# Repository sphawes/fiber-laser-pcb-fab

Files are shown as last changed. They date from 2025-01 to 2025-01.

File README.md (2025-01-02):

# How to make PCBs on a Fiber Laser

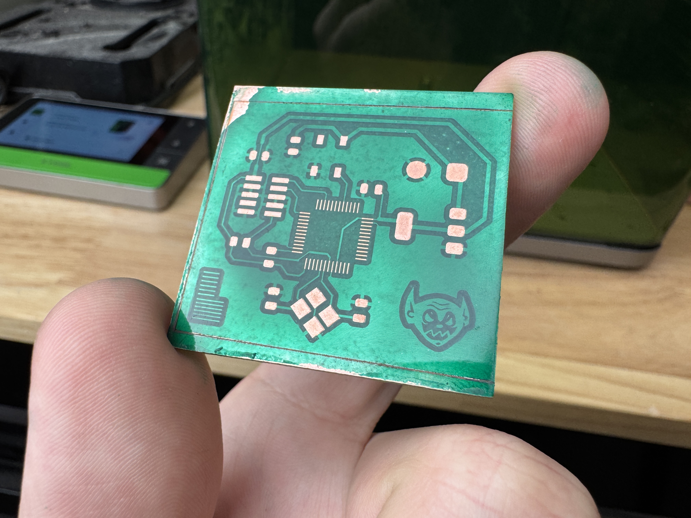
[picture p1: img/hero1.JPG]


This repo contains instructions and settings for fabricating single-sided PCBs on an xTool F1 Ultra fiber laser.

## Parts Needed

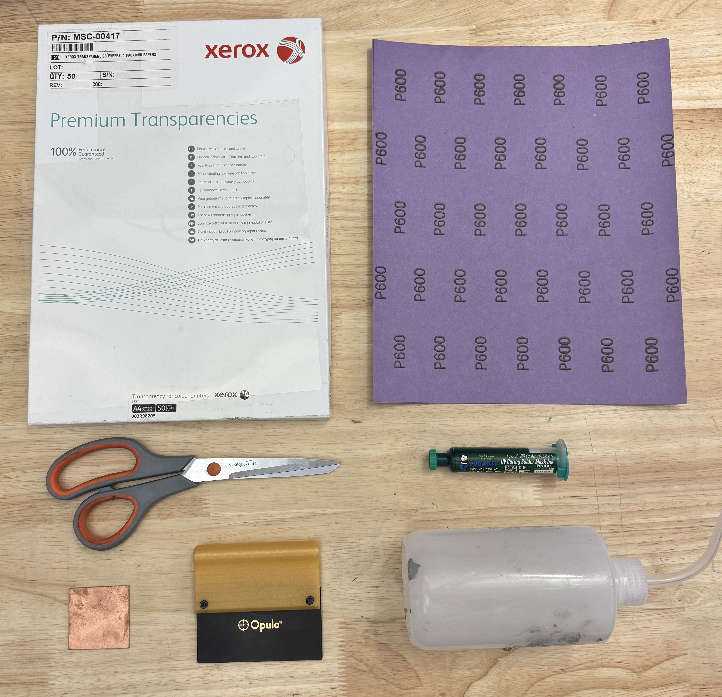
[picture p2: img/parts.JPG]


Aside from the fiber laser, you'll need:

- A transparency sheet (or framed silkscreen)
- 600 grit sandpaper
- Scissors
- Soldermask
- FR1 Copper Clad Board
- Squeegee / scraper
- Isopropyl Alcohol

You can also download and 3D print the jig for cutting and aligning boards for the F1 from this repository. You'll just need some M4 bolts, 2mm dowel pins, and [this heatsink](https://amzn.to/4a2UuFx).

## File Prep

In order to have the xTool software correctly process your files, there's some specific settings for exporting your boad that will render the correct image.

1. In KiCAD, go to `File -> Plot`.
2. Switch `Plot Format` to "DXF." Only include the F.Cu layer. Under `DXF Options`, check `Plot graphic items using their contours` and `Export Units` to "Millimeters." Make sure you've selected "Edge.Cuts" under "Plot on All Layers" not shown in this screenshot, you'll have to scroll down. This will help with alignment later. Click the `Plot` button.

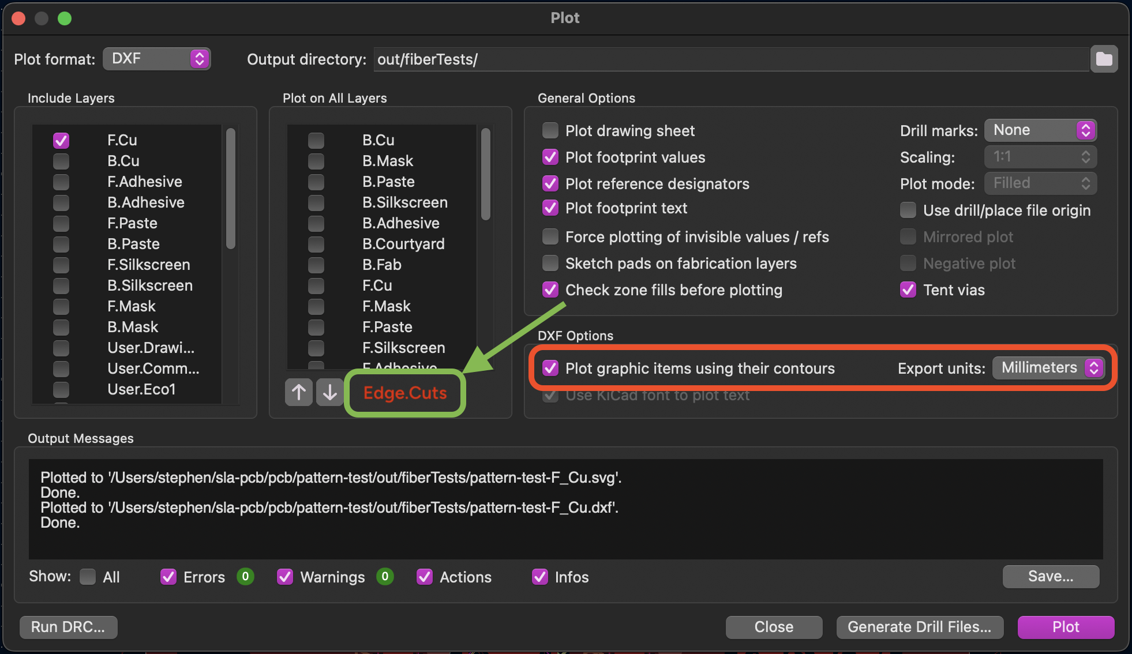
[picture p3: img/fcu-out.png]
    

1. With the same settings, select only the `F.Mask` layer and click the `Plot` button.

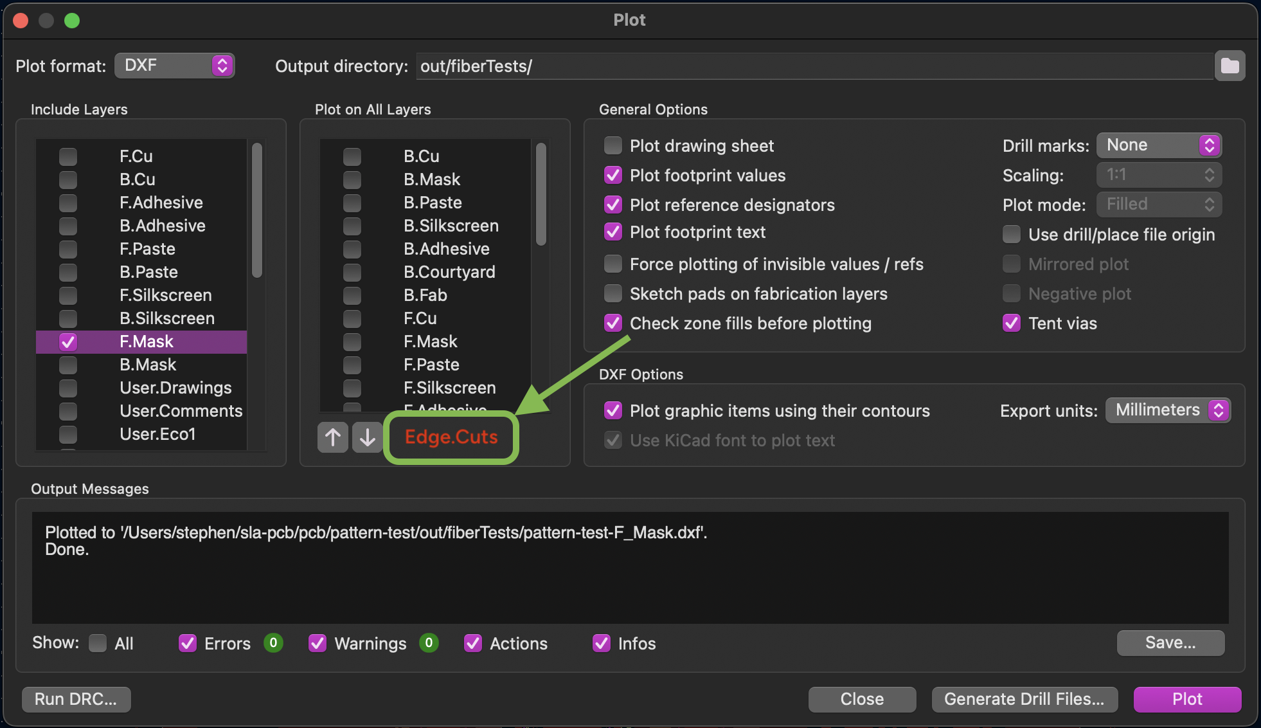
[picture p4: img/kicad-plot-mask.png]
    

## Removing Copper

1. Give your board a good sanding. While not strictly necessary, it helps quite a bit when inspecting the board and determining trace quality.

2. Mount the alignment bracket in the location that puts your board as close to the exact center of the work area as possible.

    

3. Pick the most square corner, and push it into the corner, making sure it does not come away from the bracket when pulling your hand away.

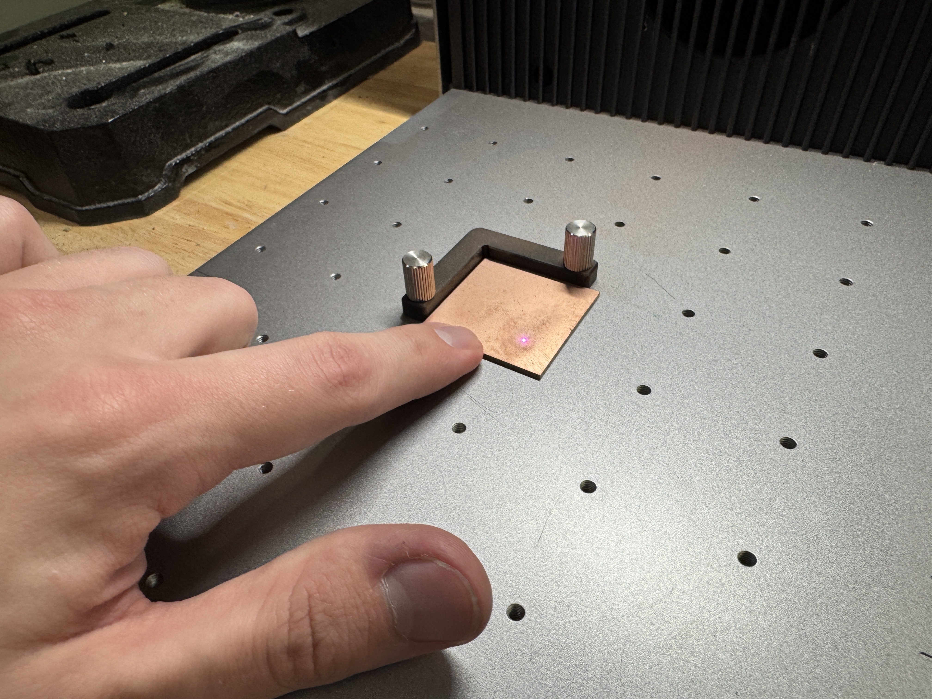
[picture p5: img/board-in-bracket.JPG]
    

4. **Gently** slide down the cover, as to not disturb the board's position.

5. In xTool Create, import the front copper DXF you exported. It should look like the image below.

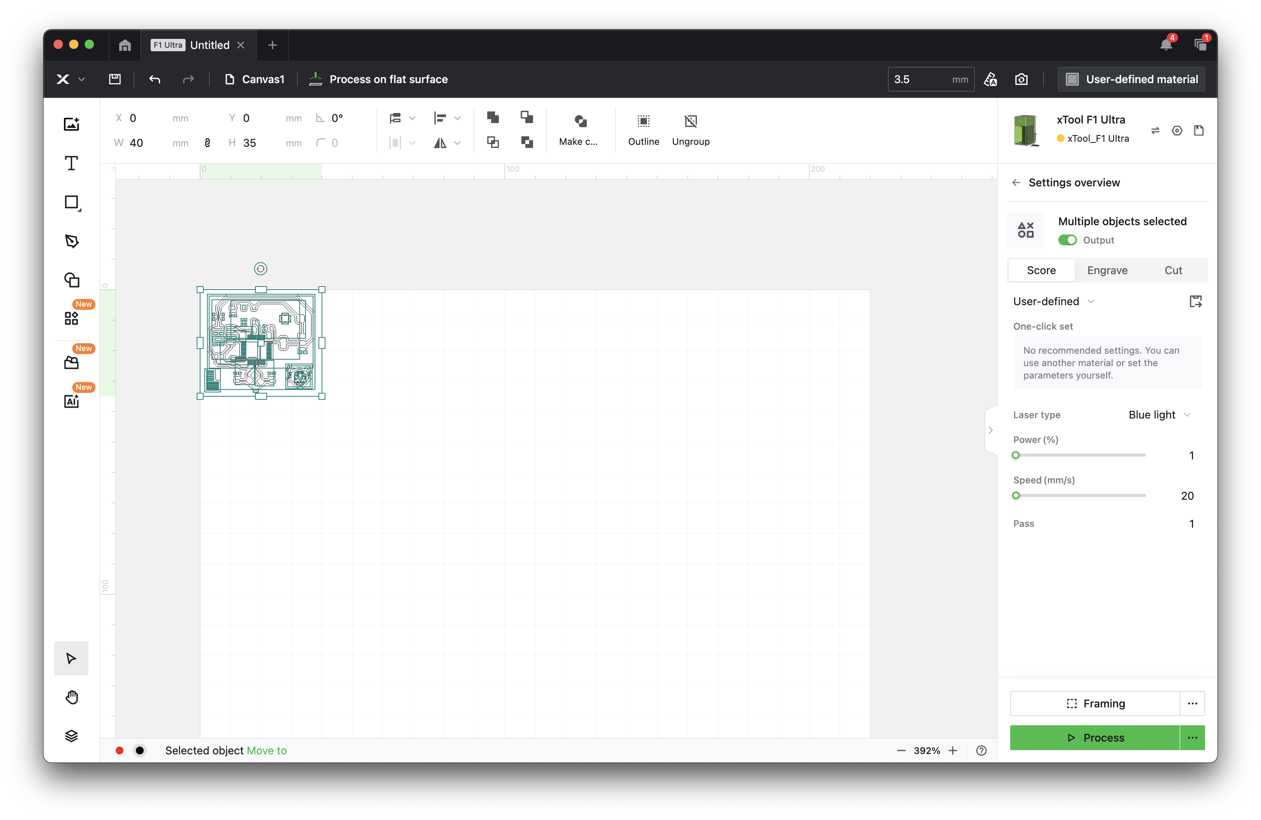
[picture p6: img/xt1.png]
    

6. Select your imported design and select the `Ungroup` button

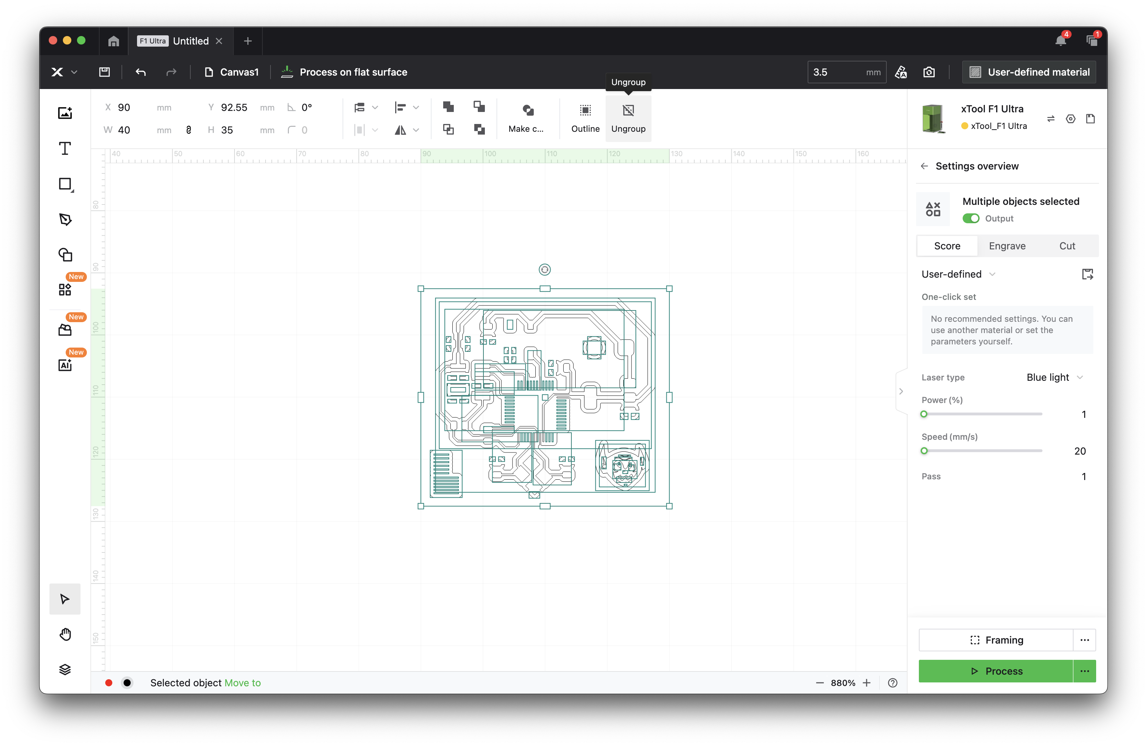
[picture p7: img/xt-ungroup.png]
    

7. With the design components ungrouped, select the outer edge cuts line, right click, and move it to a different color. I choose red for this step

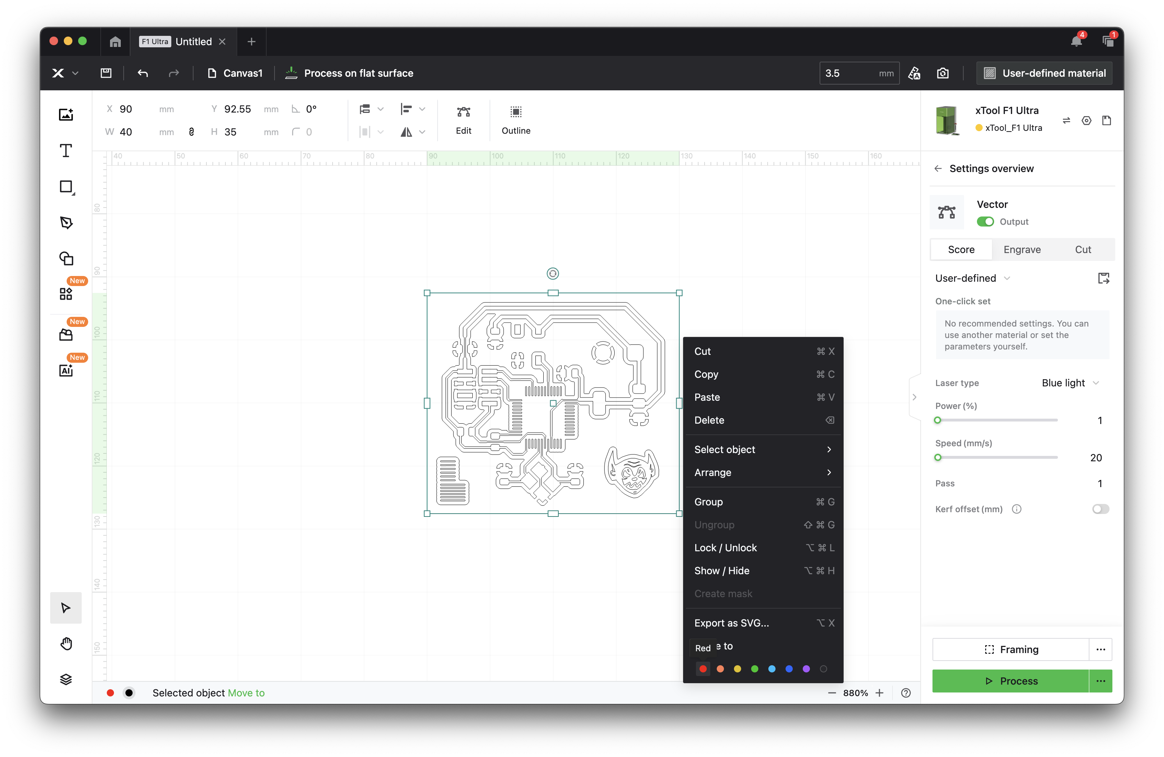
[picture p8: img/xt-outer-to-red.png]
    

8. Select all the inner components of the design (I do this by selecting *all*, then shift-clicking the outer edge).

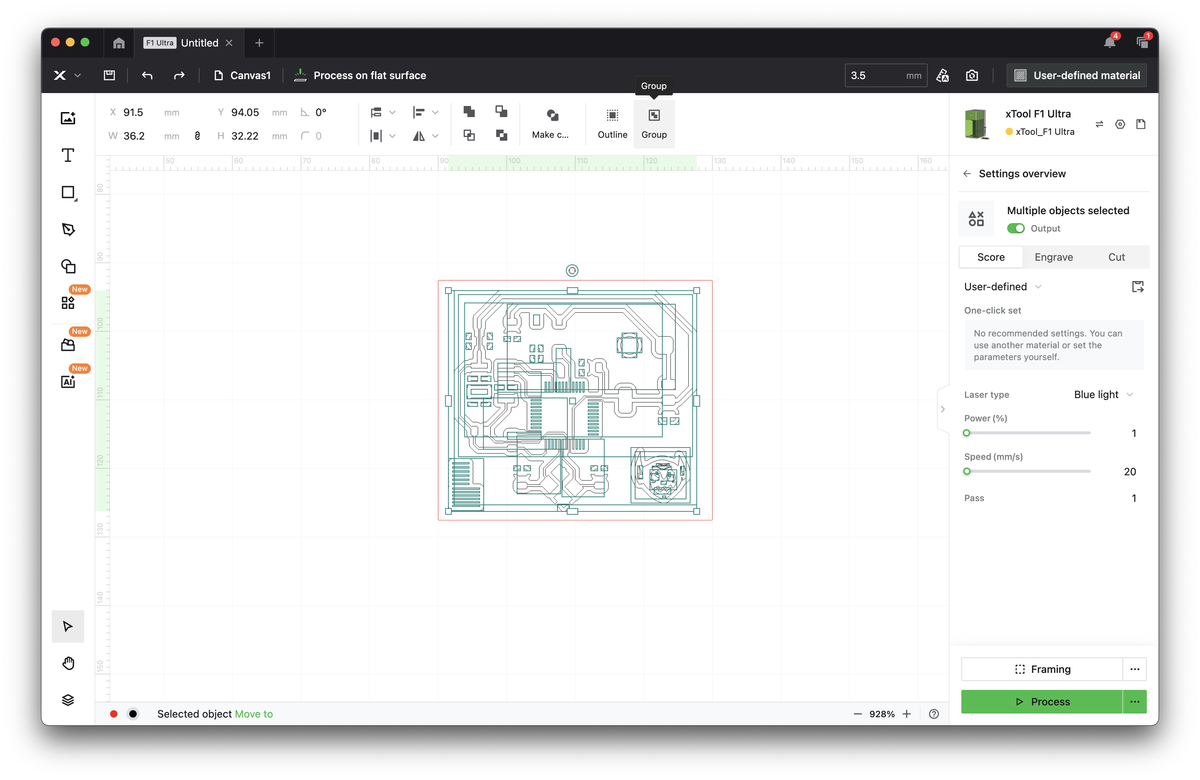
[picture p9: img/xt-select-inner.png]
    

9.  Combine all of the inner design components by clicking the `Make Compound Vector` button.

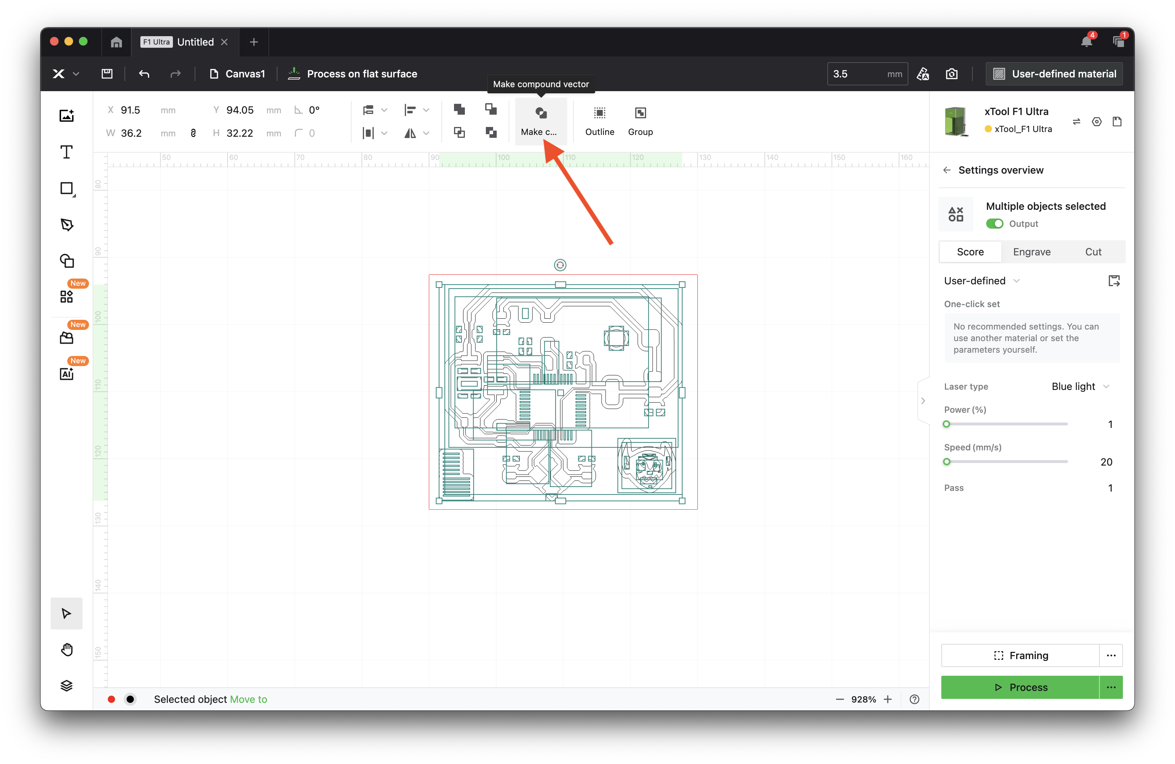
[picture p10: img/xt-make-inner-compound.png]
    

10. With the center selected, select the `Engrave` option on the right, and the board should be filled in and look like the image below:

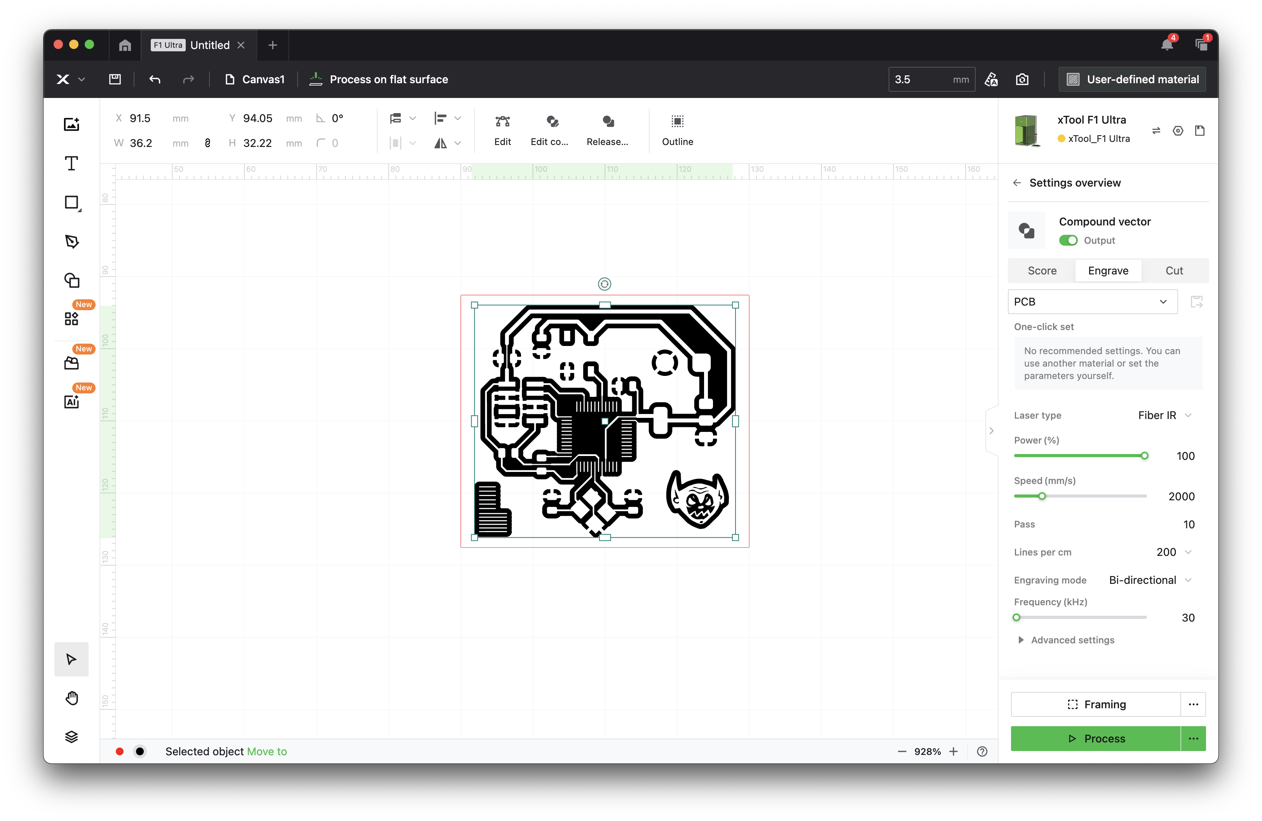
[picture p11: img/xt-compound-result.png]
    

11. Import the `settings.json` file in this repository using the settings manager.

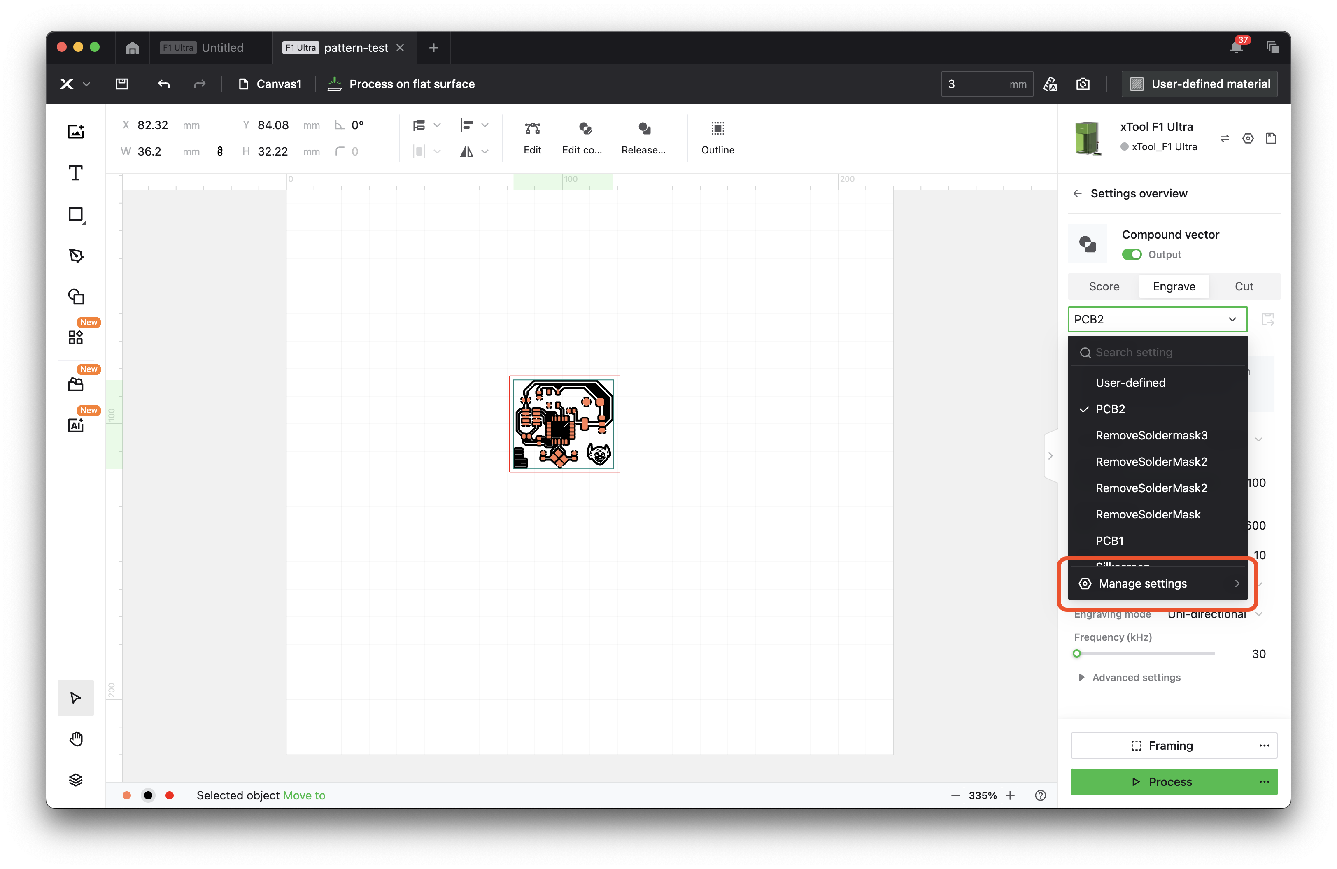
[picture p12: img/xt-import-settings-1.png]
    
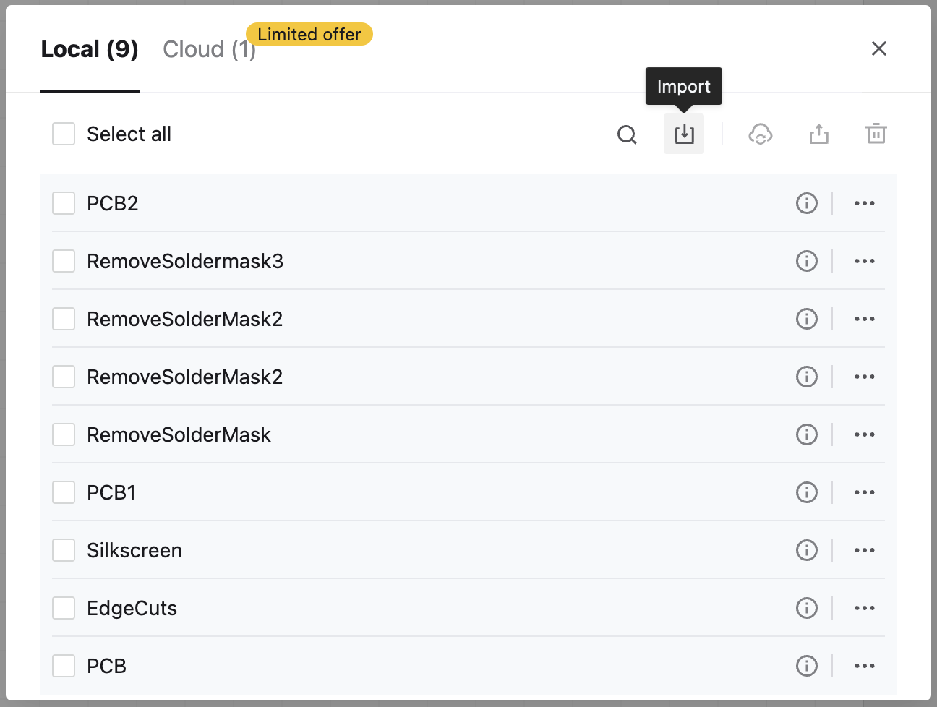
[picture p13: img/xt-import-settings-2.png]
    

12. For the inner section, select the `Traces` settings. They're also shown below if you don't want to import them directly.

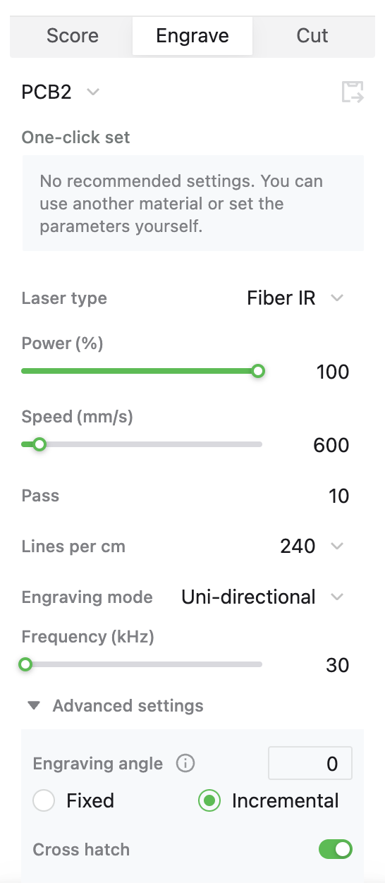
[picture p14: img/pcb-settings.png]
    

13. Use the "Capture Image" feature and the "Framing" feature to align your design onto the copper clad you put in the machine.

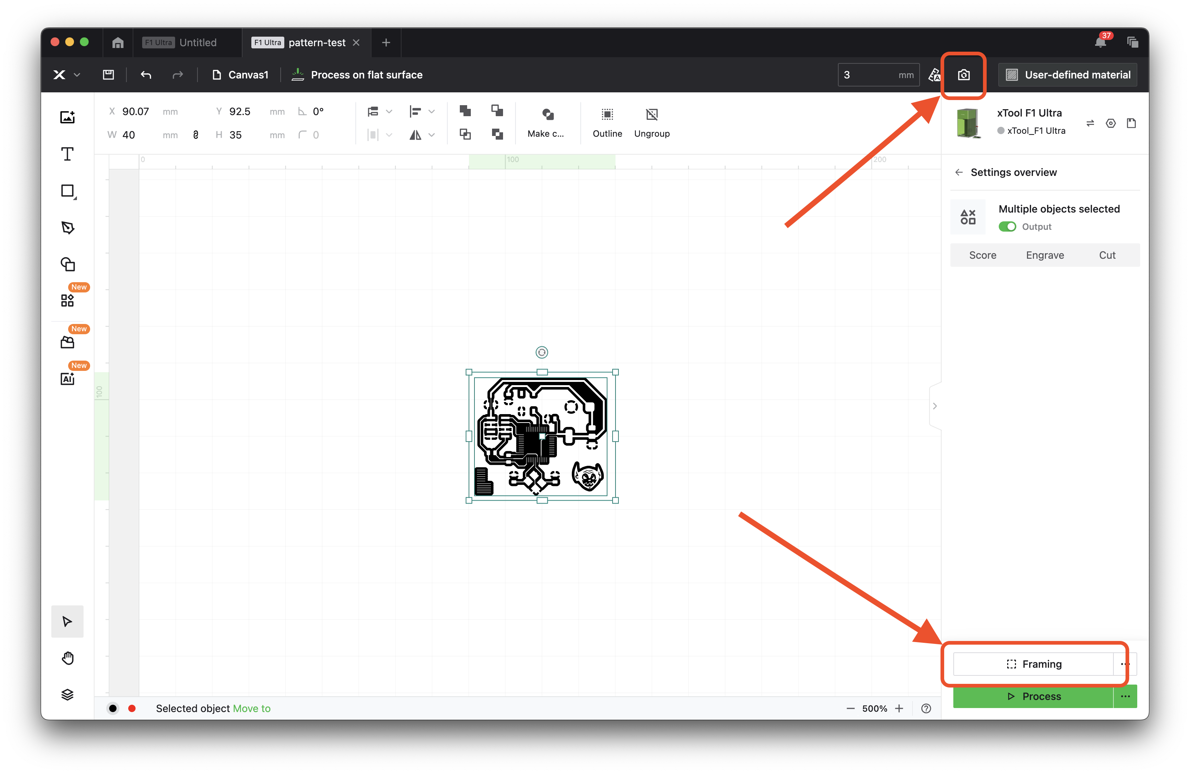
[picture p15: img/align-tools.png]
    

14. Run the job!

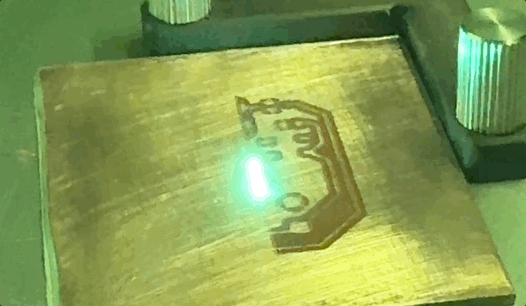
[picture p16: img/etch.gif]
    

## Board Clean

1. Your board will have some flashing and burrs on the edge of the engravings. Use some 600 grit sandpaper to remove the rough edges. you should have a smooth, clean, copper result.

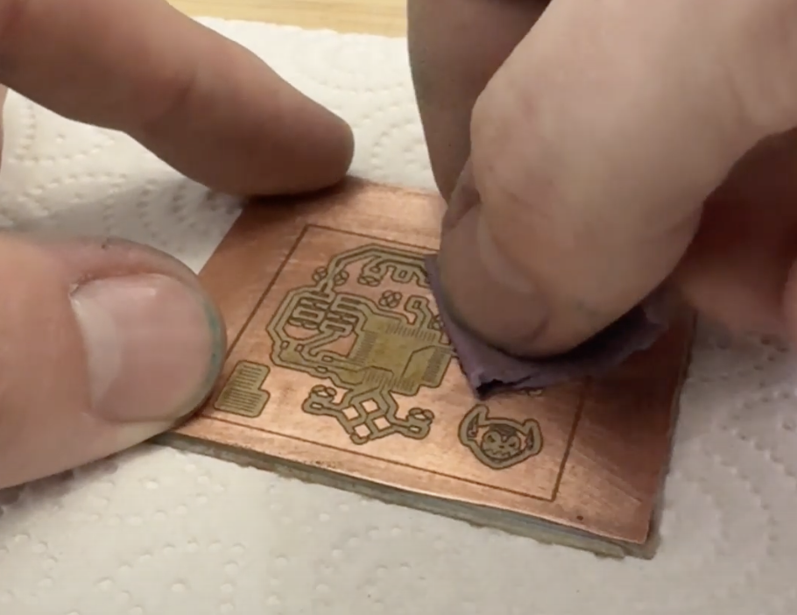
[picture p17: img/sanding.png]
    
    

1. Clean your board with Isopropyl alcohol to remove any debris and dust.

## Apply Soldermask

1. Acquire UV curable solder mask. I recommend [Mechanic Solder Mask](https://amzn.to/3DEGndt). It cures well and applies easily.

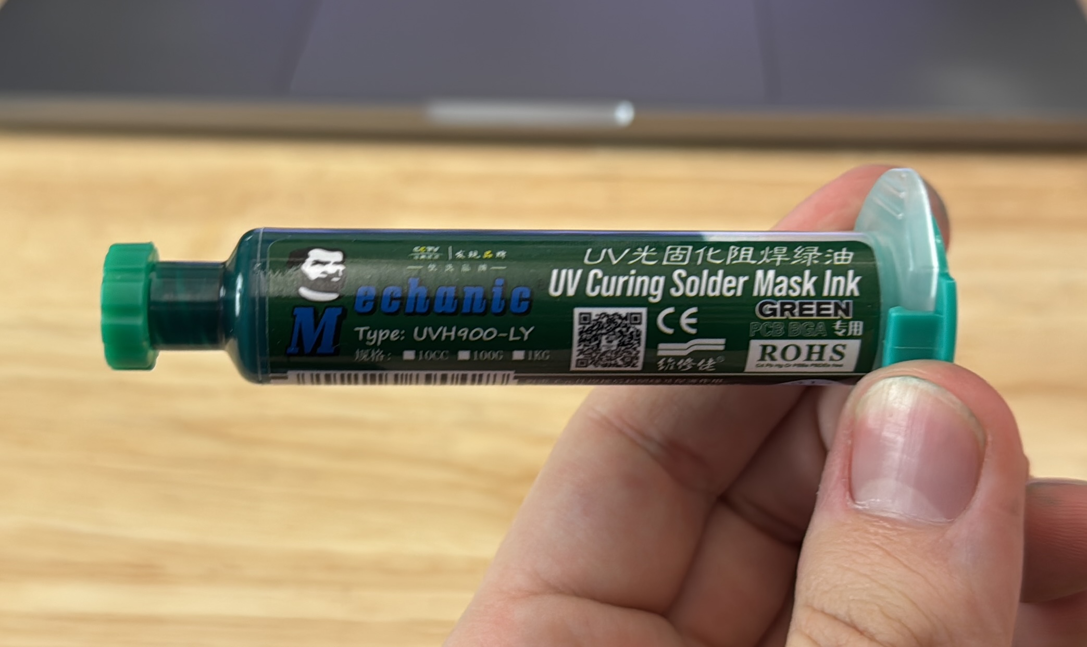
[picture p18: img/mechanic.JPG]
    

1. Apply a bead across the board.

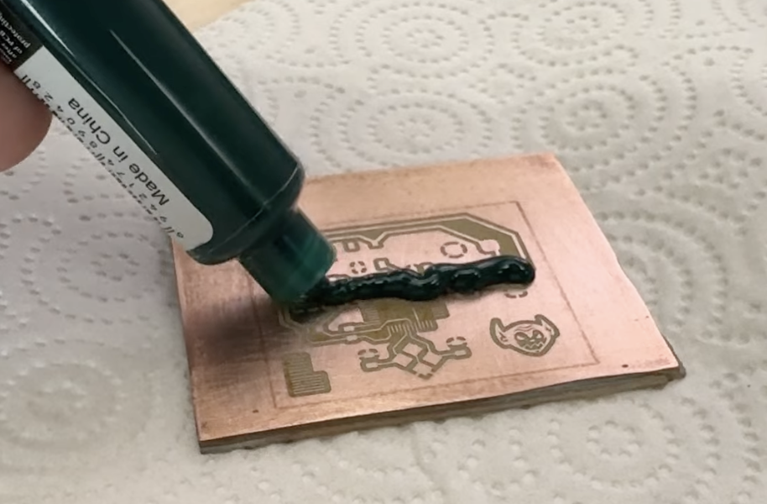
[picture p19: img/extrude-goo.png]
    

1. Place a transparency sheet on top.

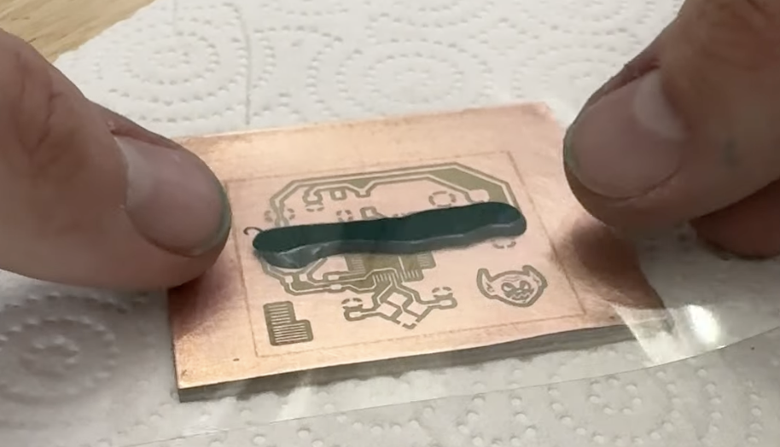
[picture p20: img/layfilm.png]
    

1. Squeegee it as evenly as possible across the board.

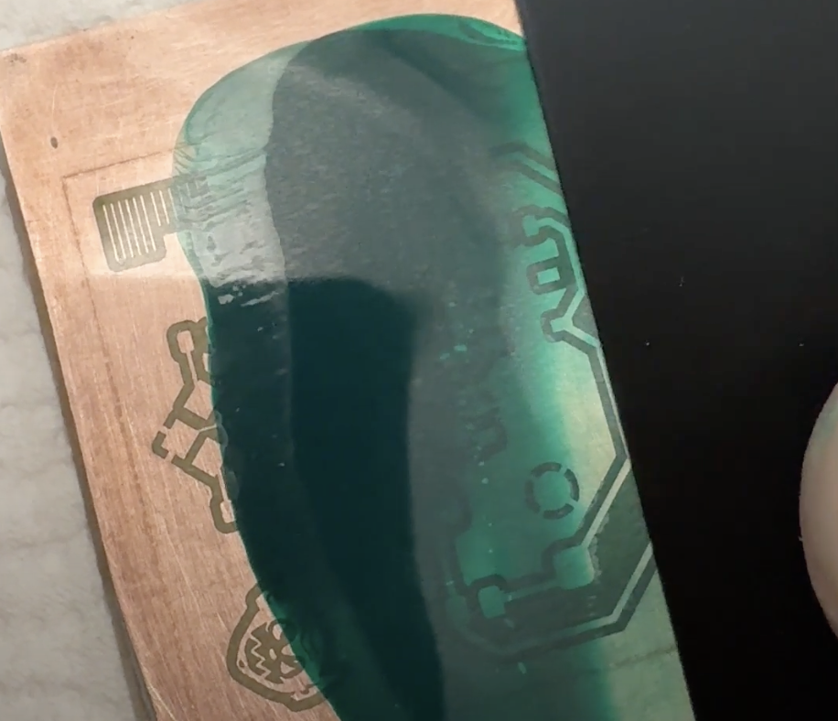
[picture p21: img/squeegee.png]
    
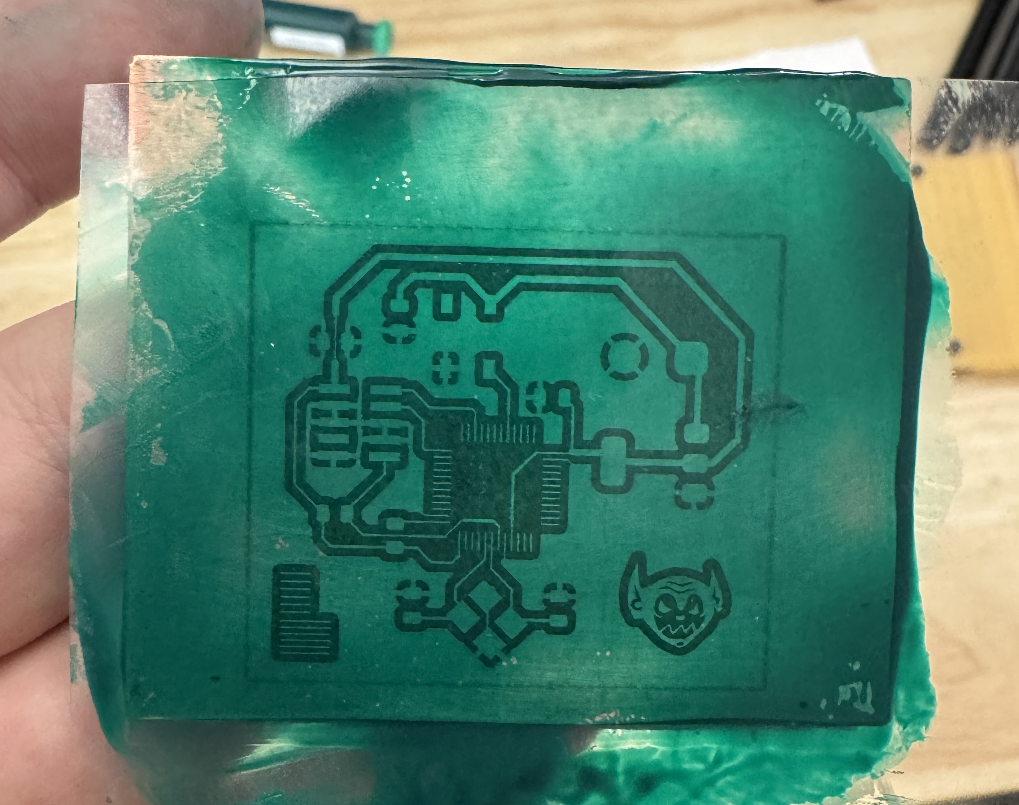
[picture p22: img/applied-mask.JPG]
    

1. An alternative solution is to use a [silkscreen frame](https://amzn.to/4fJWfZw). In my experience, this is a much more consistent way of applying the mask, and you get a nice matte finish after curing.

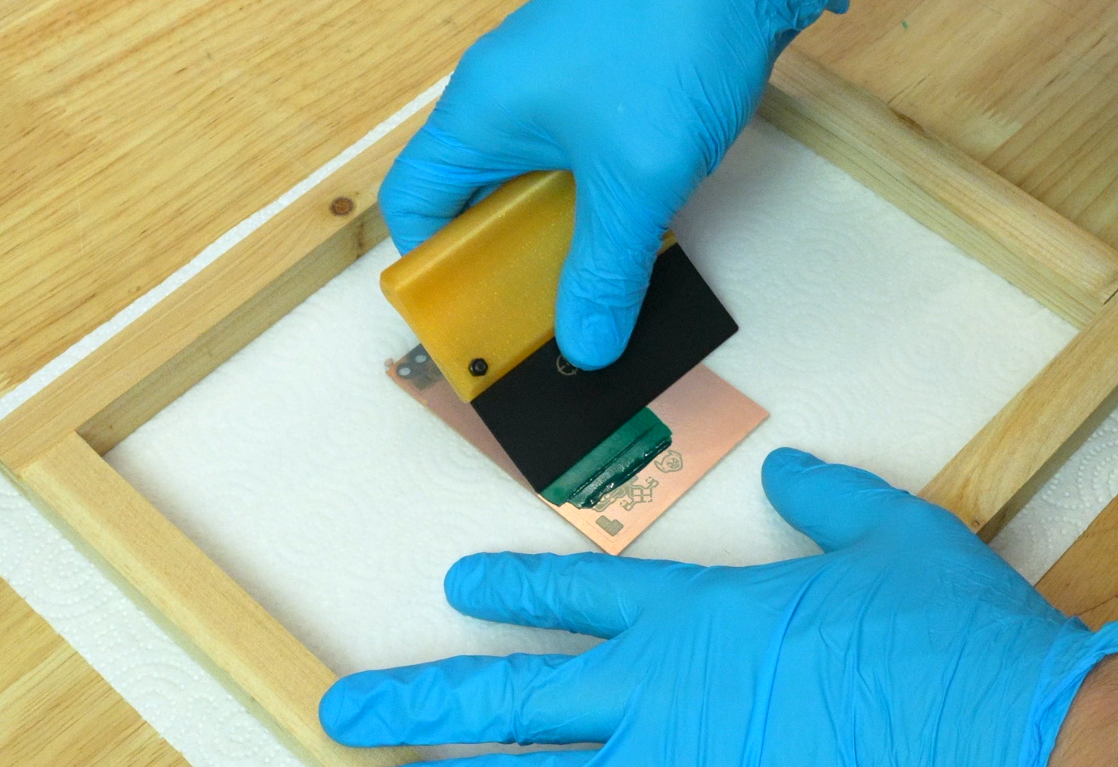
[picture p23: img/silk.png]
    
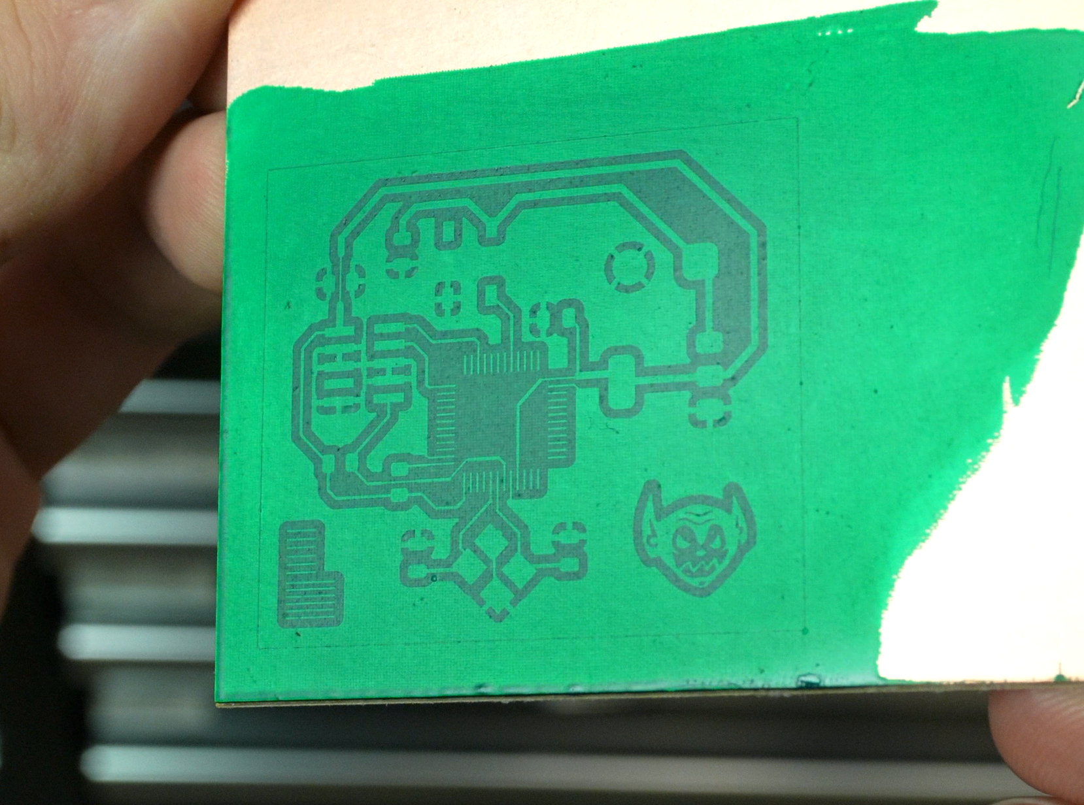
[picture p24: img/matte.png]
    

2. Cure the soldermask. A great, cheap solution is a UV nail polish curing station. [This one](https://amzn.to/3C092ZN) worked great for me.

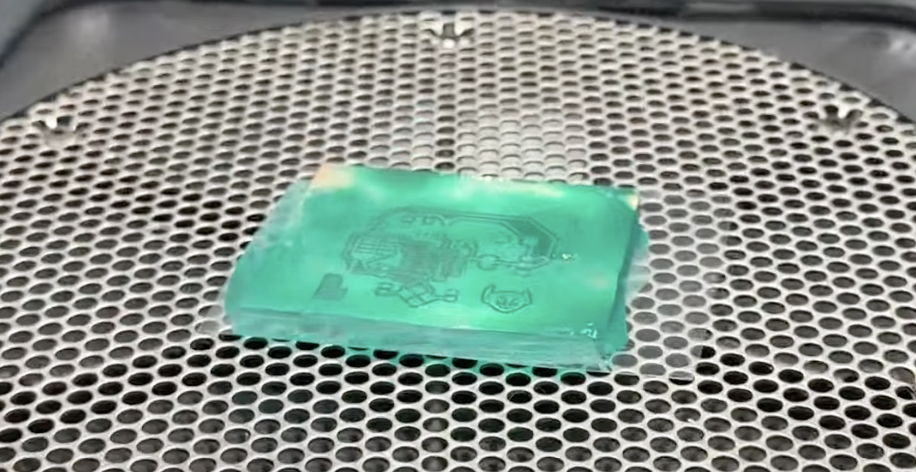
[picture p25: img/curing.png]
    

## Removing Soldermask

1. Import the F.Mask DXF you exported.

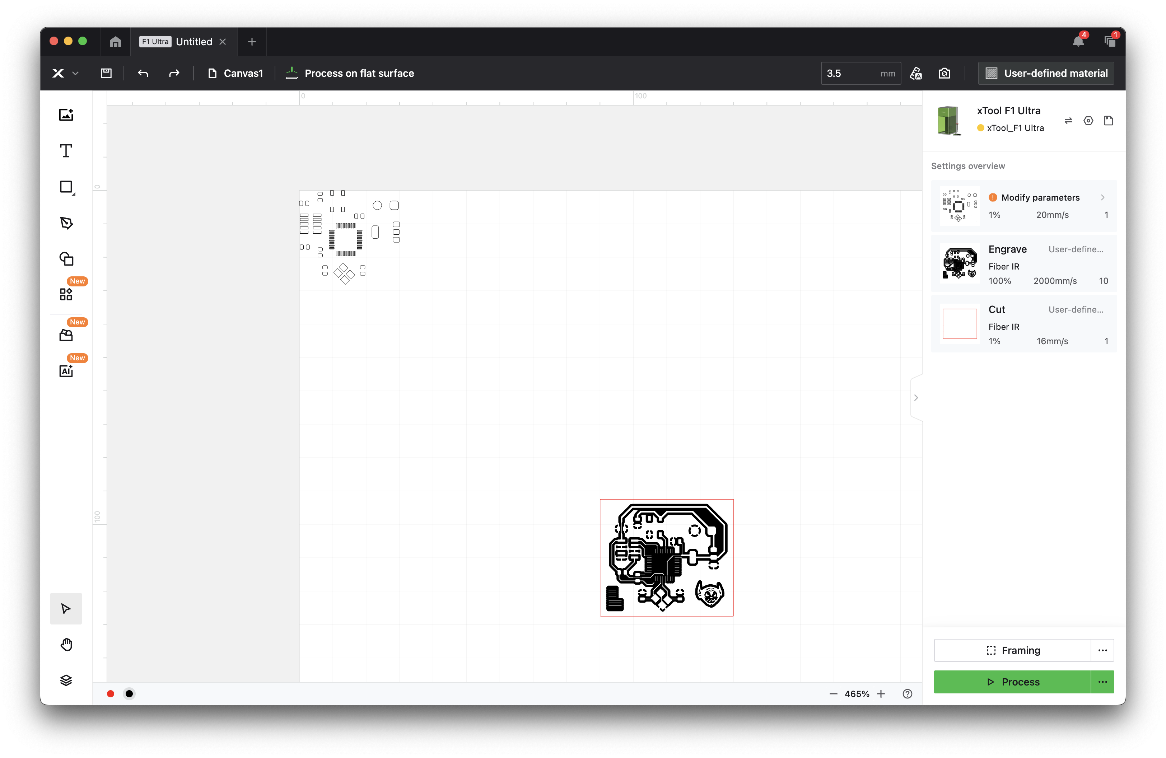
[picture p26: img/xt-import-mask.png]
    

1. Select all mask components, then combine them using the button along the top toolbar, and select the "engrave" job type in the menu on the right.

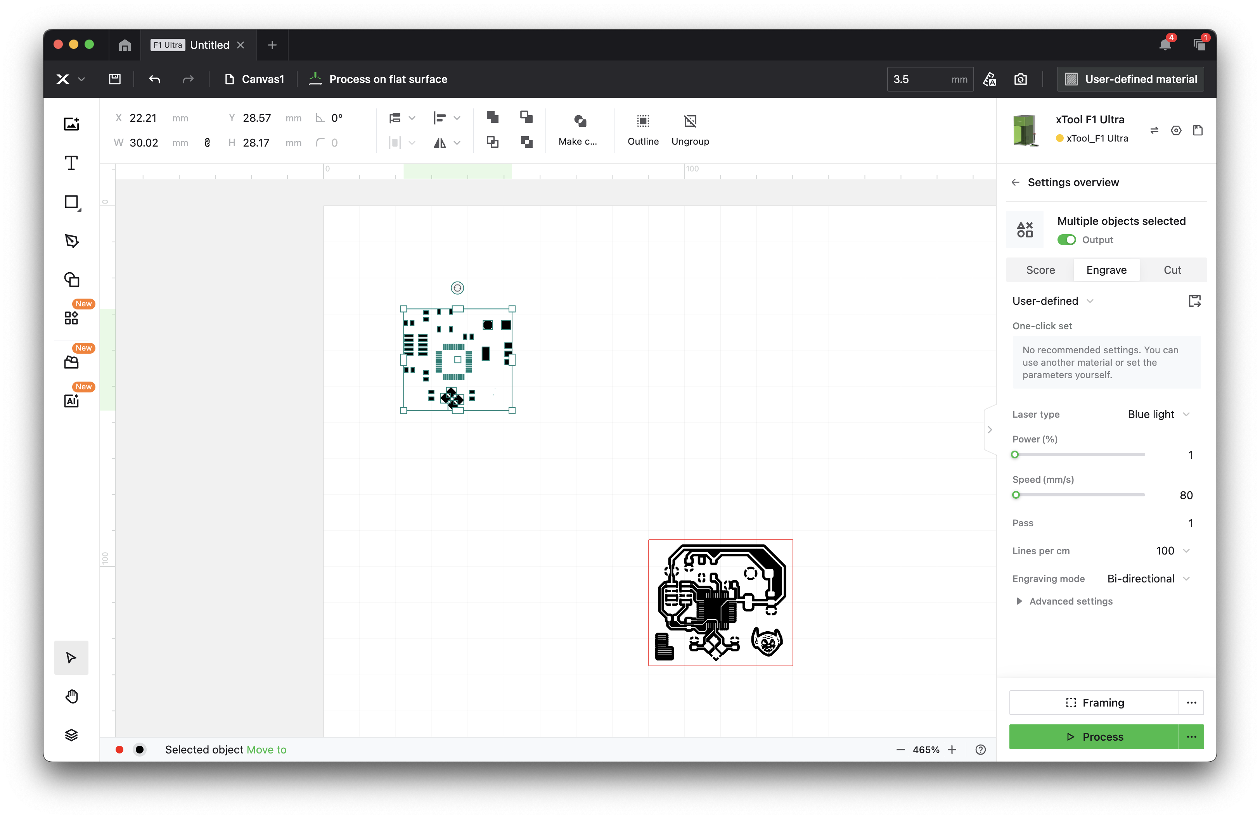
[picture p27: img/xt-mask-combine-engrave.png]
    

1. Then right click and move it to orange.

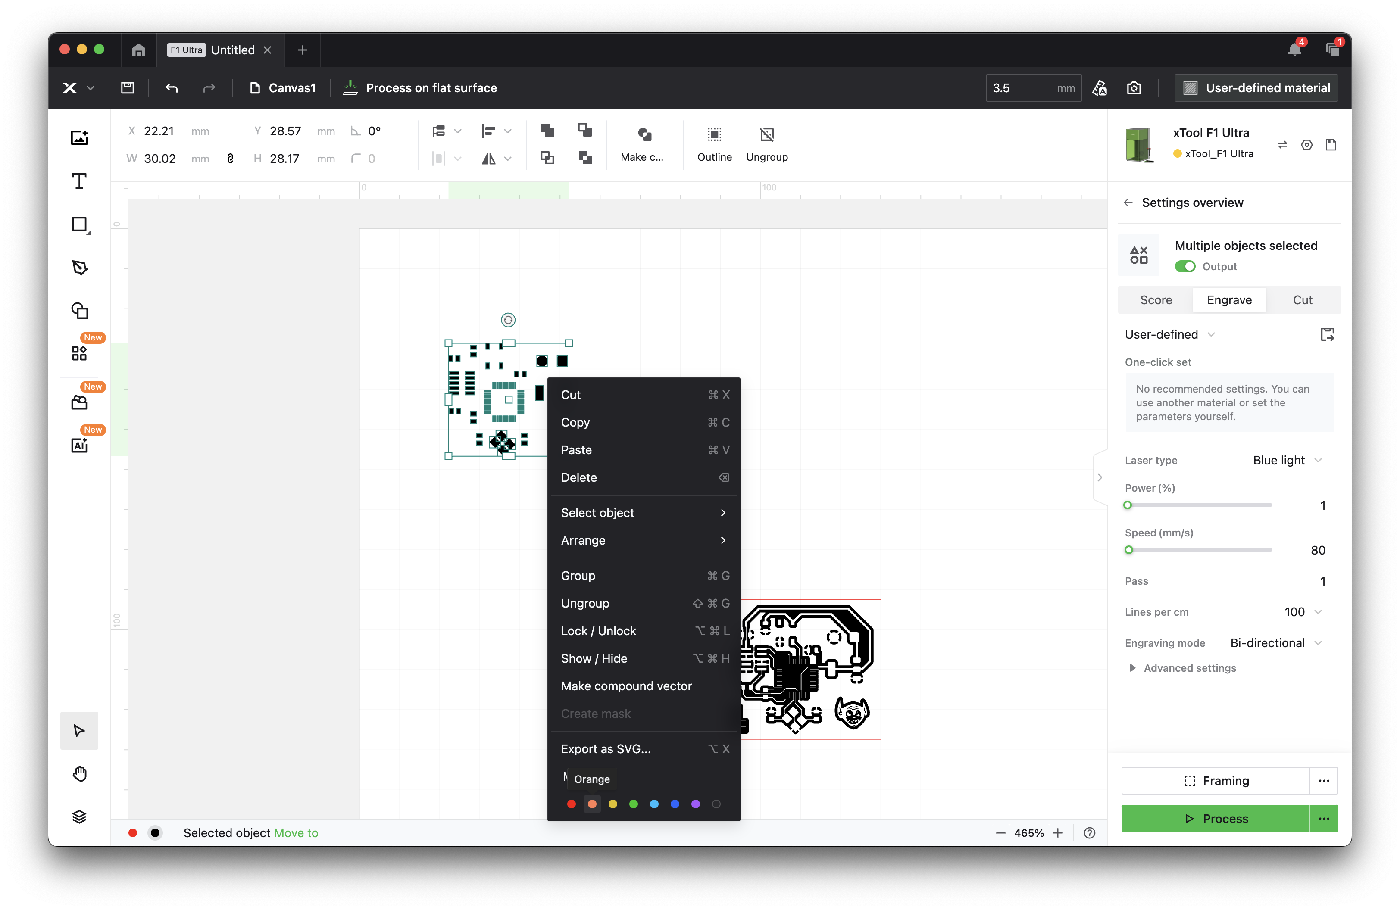
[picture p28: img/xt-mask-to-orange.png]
    

1. Align the mask on top of the existing board.

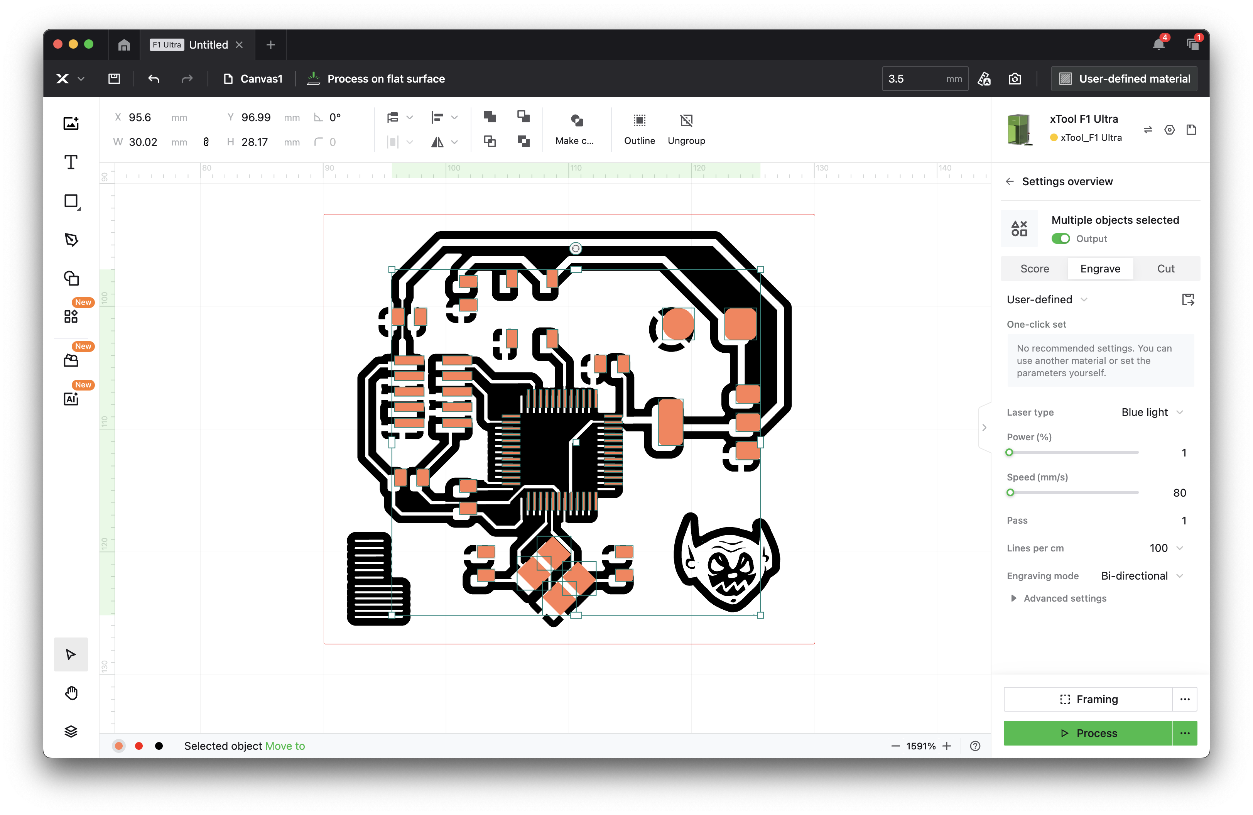
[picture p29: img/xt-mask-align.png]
    
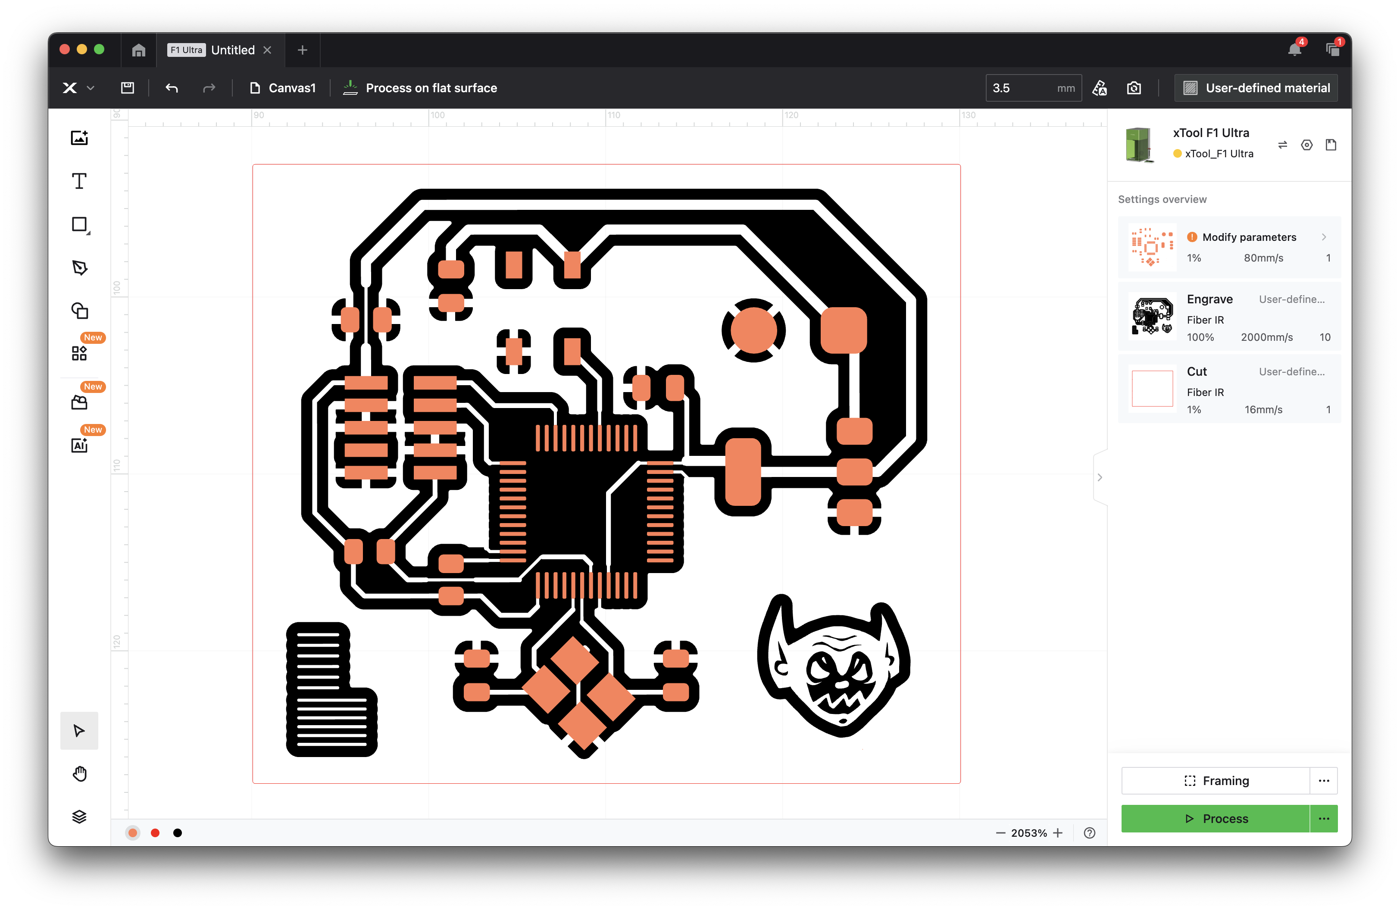
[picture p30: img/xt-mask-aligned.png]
    

1. Select the `RemoveSolderMask` settings for the orange design. They're also shown below if you don't want to import them directly.

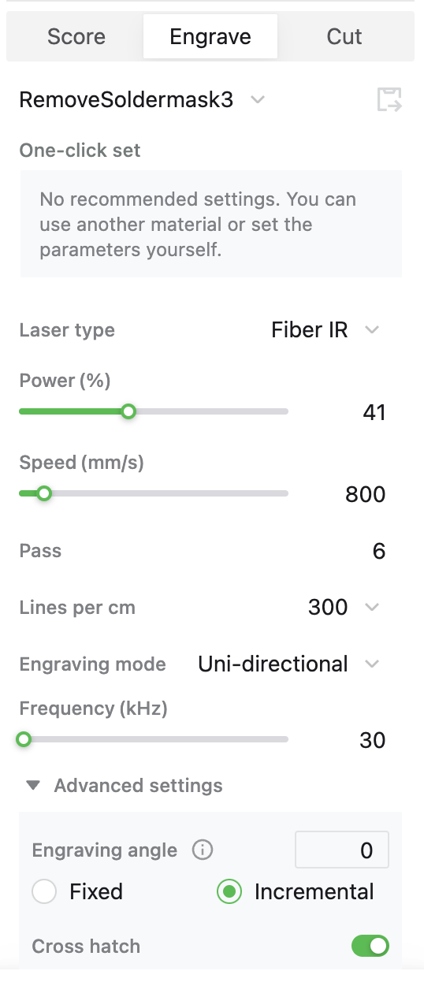
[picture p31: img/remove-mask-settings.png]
    

2. Disable the inner copper etch, and enable the edge cuts and the remove mask.

1. Do your best to reindex the board into the bracket. Use the framing tool in xTool's software to check alignment.

3. Run the job!

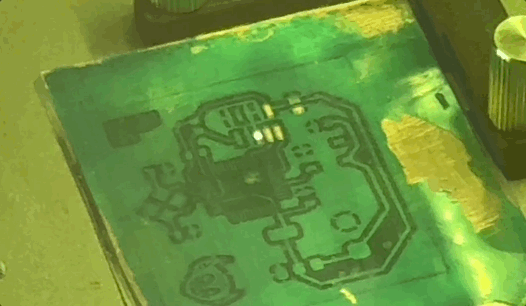
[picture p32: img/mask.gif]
    

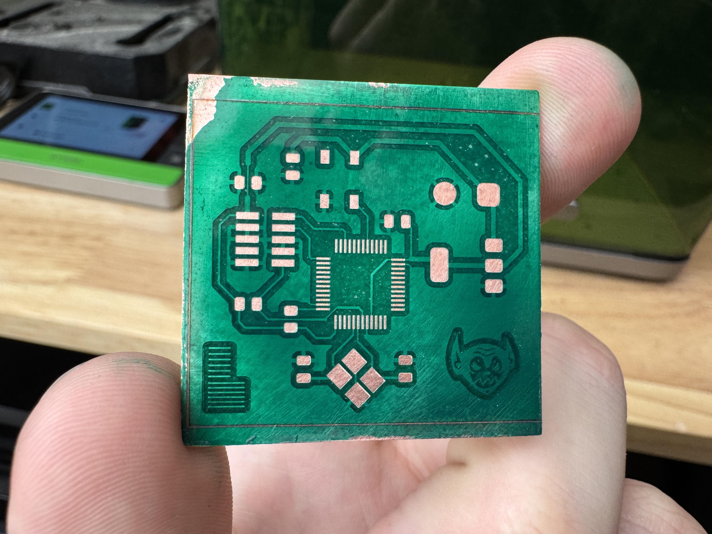
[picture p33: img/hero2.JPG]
    

## Cutting

1. Select the outer edge and select the `Cut` job type, and the `Cut/Drill` settings. They're also shown below if you don't want to import them directly.

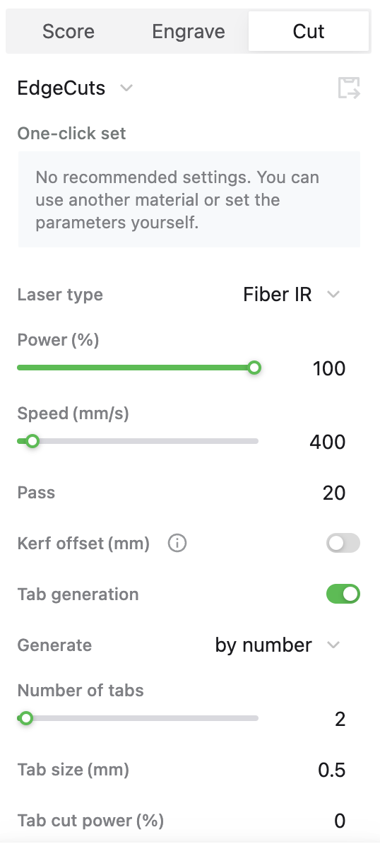
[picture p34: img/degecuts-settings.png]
    

## Done

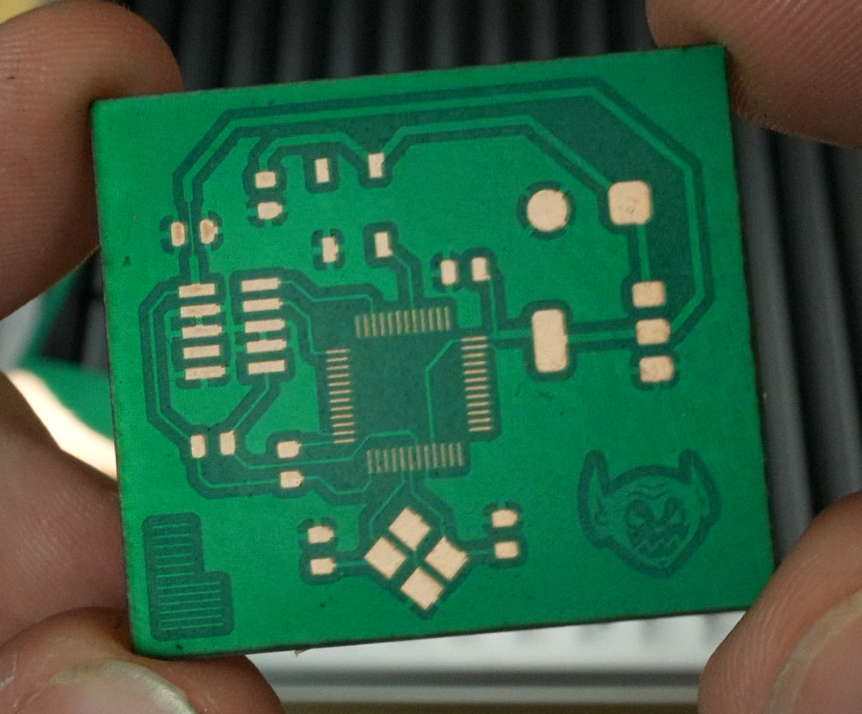
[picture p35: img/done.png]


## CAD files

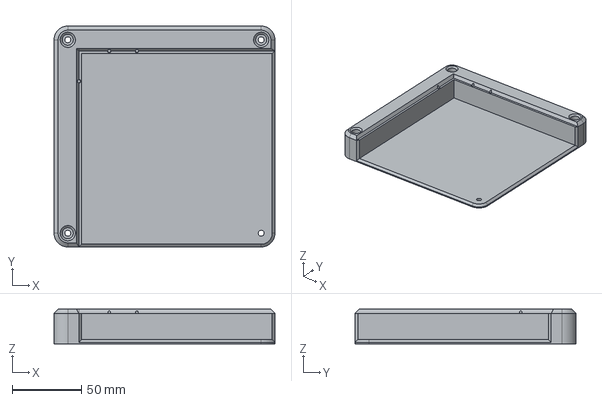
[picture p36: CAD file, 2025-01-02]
f1-pcb-mount.step
160.0 x 160.0 x 25.0 mm

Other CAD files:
f1-pcb-mount.FCStd

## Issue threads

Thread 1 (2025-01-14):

Cannot consistently etch copper

Shirtsy, 2025-01-14:
I tried the settings you suggested on my own F1 ultra and the copper etch is highly inconsistent, sometimes only very lightly engraving the surface for one or two layers before the laser seems to lose effectiveness, or sometimes leaving almost no mark at all.

I've found that adjusting the focal point to be about 3mm above the board seems to work for some reason, but this is obviously not an ideal solution due to the loss in resolution. I have of course tested on a variety of other materials and this quirk only seems to be present with the various PCB substrates I've tried, the focus appears to be correctly set when etching or cutting anything else.

Was there any particular trick to getting a consistent copper etch?

joshop, 2025-02-01:
YMMV but when I tried this, I had to very extensively clean the FR-1 board I was using with IPA and fine-grit sandpaper, there must have been some kind of protective layer on top. Without doing this, it barely even made a visible mark on the copper. Worth noting was that I was actually able to use FR-4 with the machine with no difficulties whatsoever, as long as I cleaned the board well afterwards, so you could give that a try too.

timbot, 2025-02-03:
@joshop how long did you spend cleaning/sanding the board?

I've tried sanding/cleaning some Bantam FR-1 for up to a minute and it just seems to etch for the first 1-3 passes. After that, there is no visible effect from the laser, and there's still a lot of copper left (tested by measuring continuity - the whole plane is still connected).

timbot, 2025-02-04:
Last night I had a (figurative and literal) breakthrough - I was able to get to the substrate layer by running multiple rounds of engraving and cleaning the board in between.

I'm running more experiments but I suspect copper particulate is building up on the board and I need more airflow to clean it out. I am not running an AP2 at the moment, but I am guessing @sphawes is.

I am also going to try different speeds (power is maxed out in the example settings), etc.

timbot, 2025-02-07:
Reporting back after more experimentation: the boards really need to be roughed up. Try using a heavier (lower grit) sandpaper like 400 or 320, and going in spirals. I was finally able to engrave/cut some single sided FR-1 I had lying around that in it's untouched state would barely even register a spark.

I'm going to try using an orbital sander and various grit sizes, along with maybe a jig to hold the boards in place.

I don't know what FR-1 stock Stephen was using but it's definitely not the case that boards are ablatable out of the box. When smooth, they just seem to reflect/absorb the laser energy.

timbot, 2025-02-07:
Sorry to turn this into my personal blog, but here are some more updates:

This morning I was having all sorts of trouble etching the traces, and no matter what I did it didn't make a difference.

I left the machine for an hour to run an errand, came back, and just re-ran the program I'd been trying to run previously. The green flash of ablated copper lit up immediately.

After a bunch more experimentation, I've determined that the machine/board can only engrave for 6-8 minutes. If I stop the program and re-start 30 minutes later, I get another 6-8 minutes.

I am going to run some more experiments. I may have a faulty machine, or maybe the boards need to be cooled, or maybe my board configuration is messed up (I have a lot of ground planes - maybe the constant fast on/off switching is what is causing things to overheat?).

matteliot, 2025-02-07:
Fwiw- I've also tried fr-4 under a thin layer of water to no avail (though
I didn't exhaust all the settings), and various colored sharpies. The
sharpies did well but I probably need to play with the power settings- it
was burning the copper too well.

I've also tried copy foil/tape as thin as I could find without any better
result.

My further investigation says that a UV is actually way better of a
wavewength- and also there are no galvo c02 systems.

I'm trying to get .1mm traces o my jpt mopa and have been totally
unsuccessful, regardless of trace- the copper doesn't want to ablate a bit,
it's nothing unless it heats up and then it's blacked char. It works better
at the edges than the center, so I'm guessing that's heat disbursement and
may try the water idea again.

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

joshop, 2025-02-08:
It's interesting that FR-4 has been so tricky for most people, since my experience (on the F1 Ultra) was about as painless as FR-1. I had to make sure to hit it with plenty of fine-grit sandpaper and IPA beforehand, and it looks absolutely awful - the charring makes it hard to even tell if the traces are there or not. Once you sand it and IPA it again, though, it all comes off in the wash and the traces look beautiful, like below (and are actually isolated/continuous).

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

timbot, 2025-02-22:
It turned out I just had a dud F1U - it wouldn't hold full power for more than a few minutes.

xTool sent me a replacement unit and now I am able to etch / cut with Stephen's settings. Easy peasy.

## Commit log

2025-01-02 adds jig
    [f1-pcb-mount.FCStd]
2025-01-02 adds step
    [f1-pcb-mount.step]
